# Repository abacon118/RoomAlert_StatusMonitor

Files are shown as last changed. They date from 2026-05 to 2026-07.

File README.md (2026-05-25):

# Room Alert and Web Service Status Display/Monitor
ESP32 based status monitor for RoomAlert Temperature monitors and HTTP/HTTPS based web services
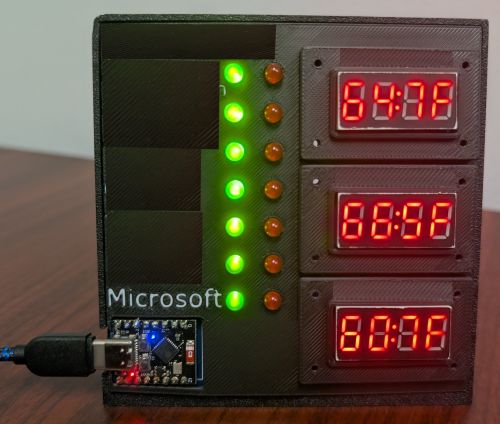
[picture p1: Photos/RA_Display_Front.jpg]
RA_Display_Front
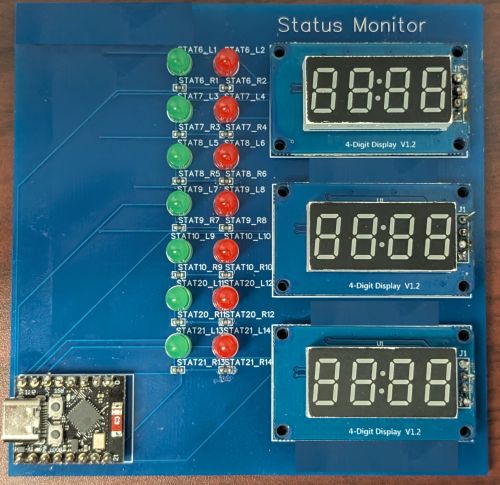
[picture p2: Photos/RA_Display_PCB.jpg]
RA_Display_PCB
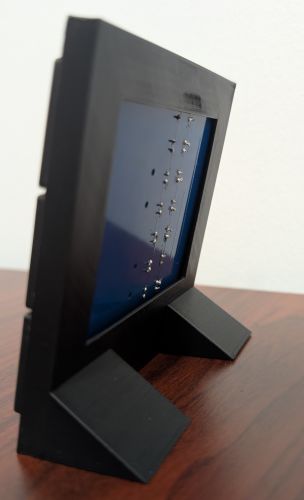
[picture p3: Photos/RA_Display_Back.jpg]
RA_Display_Back
  

## Setup
1. [Install MicroPython on ESP32](https://micropython.org/download/ESP32_GENERIC_C3/)
2. Download or copy [RA_StatusMonitor.py](/RA_StatusMonitor.py) and [config.json](/config.json)
3. Edit the following lines of config.json
     - Line 3 - Your Wifi SSID
     - Line 4 - Your Wifi Password
     - Lines 6-9 - Replace with your Room Alert links. You must create a public URL for your Room Alert device.  Paste the URL(s) in line 10 of the code.
     - Lines 11-17 - Replace with the web services/sites you wish to monitor.  Note: You can monitor services using alternate ports such as 4433, 8080, 8443, etc. as long as it uses a TCP connection.
5. Copy [tm1637.py](/tm1637.py) to ESP32.  Source: [https://github.com/mcauser/micropython-tm1637](https://github.com/mcauser/micropython-tm1637)
6. Save RA_StatusMonitor.py as boot.py on the ESP32 using Thonny or another similar IDE.

## Parts
- 3x [TM1637 4 bit 7 segment display](https://www.aliexpress.us/item/3256805913248771.html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)
- 1x [ESP 32 C3 Super Mini](https://www.aliexpress.us/item/3256807754944428.html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)
- 7x Red LEDs
- 7x Green LEDs
- 14x 220 Ohm 0603 Resistors

## Schematic
[Schematic PDF](/Gerber_RoomAlert_Generic_PCB_1-copy_2026-05-15.pdf)
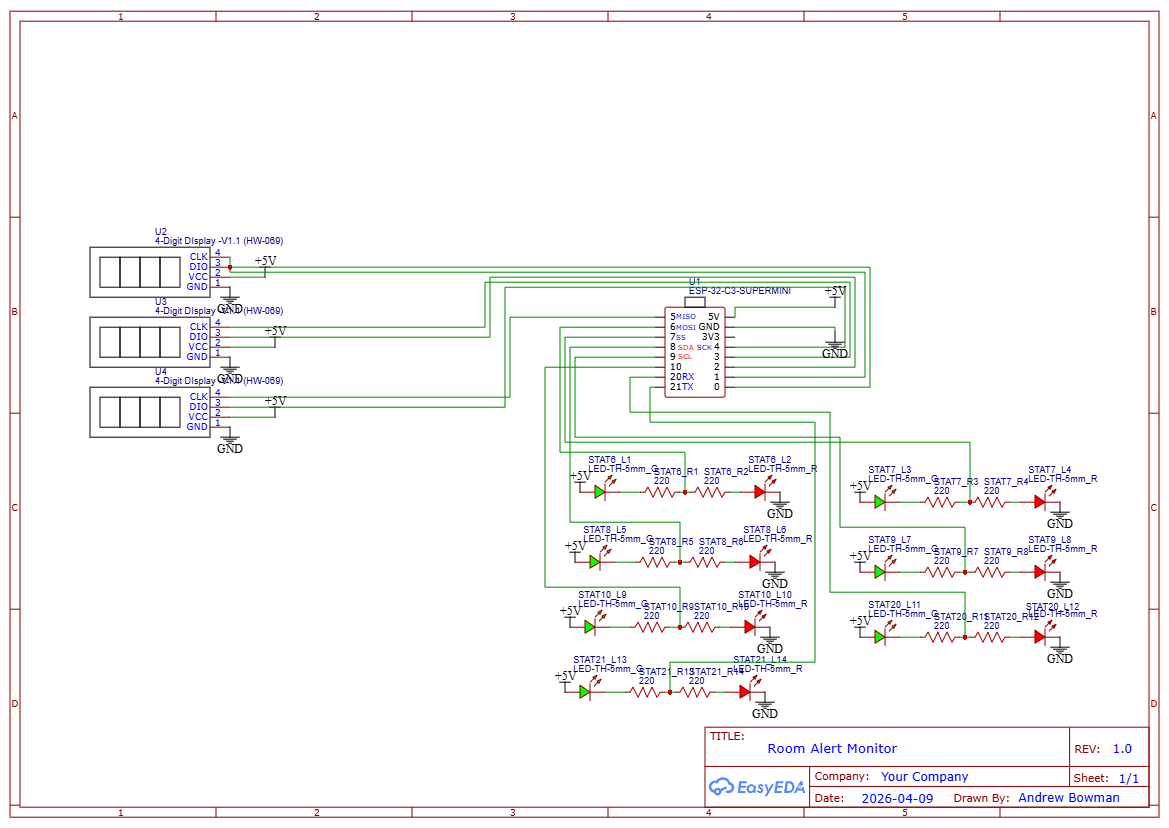
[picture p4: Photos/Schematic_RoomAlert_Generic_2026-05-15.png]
Schematic


## PCB
[Gerber ZIP](/Gerber_RoomAlert_Generic_PCB_1-copy_2026-05-15.zip)
[EasyEDA Files](/RoomAlert_EasyEDA.zip)
100mm x 100mm Standard 2 layer PCB from JLC PCB
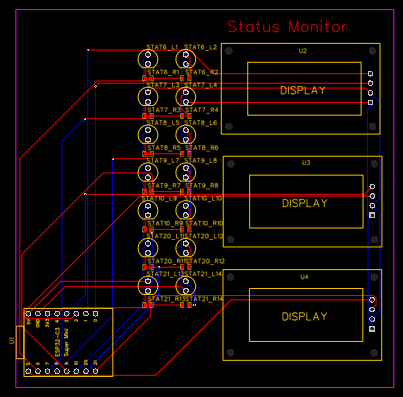
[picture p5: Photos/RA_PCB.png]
PCB


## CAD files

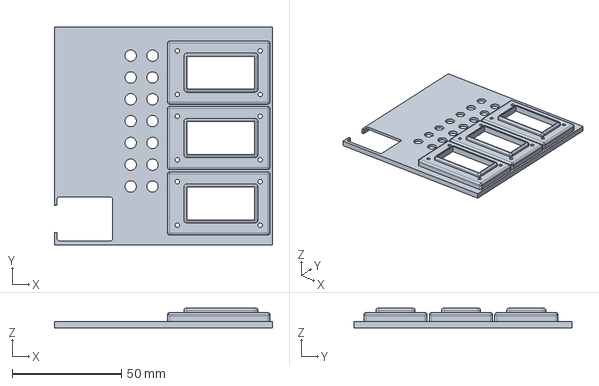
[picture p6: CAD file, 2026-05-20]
3dPrint/RA_Display_Blank.FCStd
100.0 x 100.0 x 9.00 mm

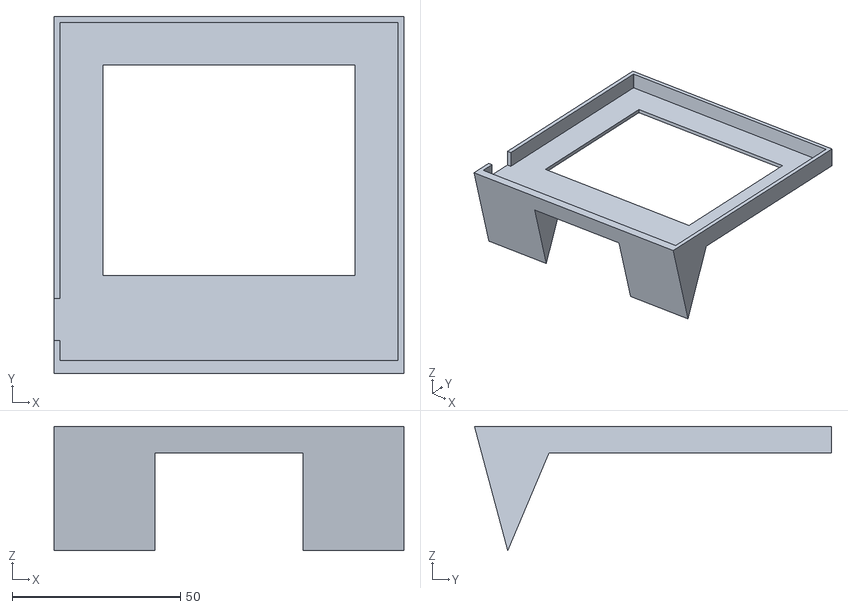
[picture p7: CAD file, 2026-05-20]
3dPrint/RA_Display_Blank-Back.stl
104.0 x 106.1 x 37.0

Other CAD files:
3dPrint/RA_Display_Blank-Body.stl

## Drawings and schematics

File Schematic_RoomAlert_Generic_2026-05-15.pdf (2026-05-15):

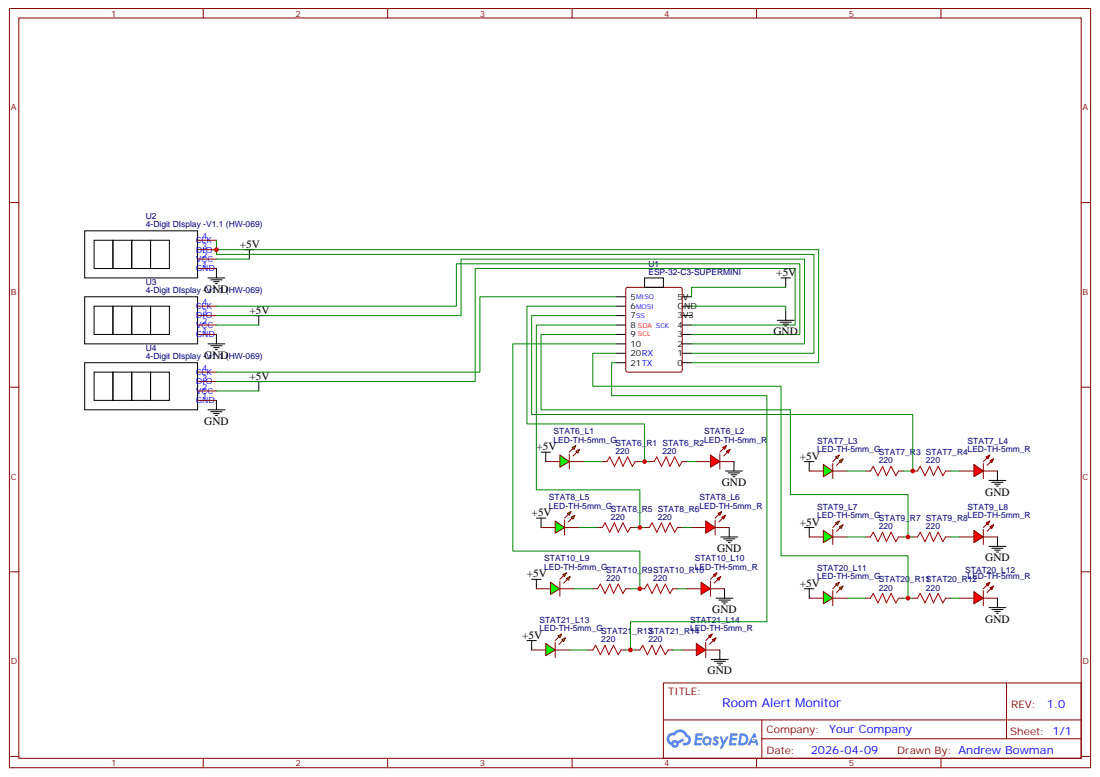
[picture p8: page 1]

Drawn By: Andrew Bowman

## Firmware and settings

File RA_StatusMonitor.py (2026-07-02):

# Room Alert ESP32 Monitor V4.2
# Andrew Bowman 2026
# https://docs.sunfounder.com/projects/umsk/en/latest/04_pi_pico/pico_lesson26_lcd.html
# https://microcontrollerslab.com/micropython-openweathermap-api-esp32-esp8266-sensorless-weather-station/
# AI assistance from Copilot was used in the creation of this.
import time
import socket
import tm1637
import _thread
from machine import Pin
tm = [
    tm1637.TM1637(clk=Pin(1), dio=Pin(0)),
    tm1637.TM1637(clk=Pin(3), dio=Pin(2)),
    tm1637.TM1637(clk=Pin(5), dio=Pin(4))
]

try:
  import urequests as requests
except:
  import requests
  
try:
  import ujson as json
except:
  import json

import network

import esp
esp.osdebug(None)

import gc
gc.collect()

led6 = Pin(6, Pin.OUT)
led7 = Pin(7, Pin.OUT)
led8 = Pin(8, Pin.OUT)
led9 = Pin(9, Pin.OUT)
led10 = Pin(10, Pin.OUT)
led20 = Pin(20, Pin.OUT)
led21 = Pin(21, Pin.OUT)

led6.value(1)
led7.value(1)
led8.value(1)
led9.value(1)
led10.value(1)
led20.value(1)
led21.value(1)

with open("config.json") as f:
    config = json.load(f)
RA_URLs = []
for entry in config["RA_URLs"]:
    RA_URLs.append({
        "url": entry["url"],
        "location": entry["location"]        
    })
PING_URLs = []
for entry in config["PING_TARGETS"]:
    PING_URLs.append({
        "url": entry["url"],
        "port": entry["port"],
        "led": Pin(entry["led"], Pin.OUT)
    })
ssid = config["wifi"]["ssid"]
password = config["wifi"]["password"]

station = network.WLAN(network.STA_IF)

station.active(True)
station.connect(ssid, password)

while station.isconnected() == False:
  pass

print('Connection successful')
print(station.ifconfig())


def print_temp(display, f):

    if f < -9.9:
        display.show('lo')
        return
    if f > 99.9:
        display.show('hi')
        return
    raw = "{:4.2f}".format(f)   # e.g. "67.7"     # Format with one decimal
    dot_pos = raw.index('.')    # e.g. 2     # Find decimal BEFORE removing it
    s = raw.replace('.', '')    # "677"     # Remove the dot
    segs = display.encode_string(s)     # Encode the digits (3 digits + 1 blank)
    segs[dot_pos - 1] |= 0x80     # Add decimal point to the correct digit
    segs[-1] = 0b01110001      # Replace last digit with raw segment pattern for 'F'
    display.write(segs)     # Write raw segments directly

def tcp_ping(host, port=80, timeout=2000):
    addr = socket.getaddrinfo(host, port)[0][-1]
    s = socket.socket()
    s.settimeout(timeout / 1000)

    start = time.ticks_ms()
    try:
        s.connect(addr)
        s.close()
        return True, time.ticks_diff(time.ticks_ms(), start)
    except Exception as e:
        return False, str(e)
    finally:
        s.close()

while(1):
    for i, entry in enumerate(RA_URLs):
        url = entry["url"]
        location = entry["location"]

        RA_data = requests.get(url)
        RA_text = RA_data.text
        RA_data.close()
        del RA_data
        gc.collect()
        #print(RA_data.text)
        marker = "                                            <b>" #Find this on line 265 in the Room Alert HTML.  The Temp is right after it.
        start = RA_text.find(marker)

        if start != -1:
            start += len(marker)
            end = RA_text.find("°F", start)
            Temp = float(RA_text[start:end].strip())
            print(location," temperature:", Temp)
            print_temp(tm[i],Temp)
        else:
            print("Temperature not found")
            
    for entry in PING_URLs:
            host = entry["url"]
            port = entry["port"]
            led = entry["led"]
            ok, info = tcp_ping(host, port)
            if ok:
                print(host, "reachable, latency:", info, "ms")
                led.value(0)
            else:
                print(host, "UNREACHABLE:", info)
                led.value(1)
            
    time.sleep(60)

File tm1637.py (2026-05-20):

"""
MicroPython TM1637 quad 7-segment LED display driver
https://github.com/mcauser/micropython-tm1637

MIT License
Copyright (c) 2016-2023 Mike Causer

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
__version__ = '1.3.0'

from micropython import const
from machine import Pin
from time import sleep_us, sleep_ms

TM1637_CMD1 = const(64)  # 0x40 data command
TM1637_CMD2 = const(192) # 0xC0 address command
TM1637_CMD3 = const(128) # 0x80 display control command
TM1637_DSP_ON = const(8) # 0x08 display on
TM1637_DELAY = const(10) # 10us delay between clk/dio pulses
TM1637_MSB = const(128)  # msb is the decimal point or the colon depending on your display

# 0-9, a-z, blank, dash, star
_SEGMENTS = bytearray(b'\x3F\x06\x5B\x4F\x66\x6D\x7D\x07\x7F\x6F\x77\x7C\x39\x5E\x79\x71\x3D\x76\x06\x1E\x76\x38\x55\x54\x3F\x73\x67\x50\x6D\x78\x3E\x1C\x2A\x76\x6E\x5B\x00\x40\x63')

class TM1637(object):
    """Library for quad 7-segment LED modules based on the TM1637 LED driver."""
    def __init__(self, clk, dio, brightness=7):
        self.clk = clk
        self.dio = dio

        if not 0 <= brightness <= 7:
            raise ValueError("Brightness out of range")
        self._brightness = brightness

        self.clk.init(Pin.OUT, value=0)
        self.dio.init(Pin.OUT, value=0)
        sleep_us(TM1637_DELAY)

        self._write_data_cmd()
        self._write_dsp_ctrl()

    def _start(self):
        self.dio(0)
        sleep_us(TM1637_DELAY)
        self.clk(0)
        sleep_us(TM1637_DELAY)

    def _stop(self):
        self.dio(0)
        sleep_us(TM1637_DELAY)
        self.clk(1)
        sleep_us(TM1637_DELAY)
        self.dio(1)

    def _write_data_cmd(self):
        # automatic address increment, normal mode
        self._start()
        self._write_byte(TM1637_CMD1)
        self._stop()

    def _write_dsp_ctrl(self):
        # display on, set brightness
        self._start()
        self._write_byte(TM1637_CMD3 | TM1637_DSP_ON | self._brightness)
        self._stop()

    def _write_byte(self, b):
        for i in range(8):
            self.dio((b >> i) & 1)
            sleep_us(TM1637_DELAY)
            self.clk(1)
            sleep_us(TM1637_DELAY)
            self.clk(0)
            sleep_us(TM1637_DELAY)
        self.clk(0)
        sleep_us(TM1637_DELAY)
        self.clk(1)
        sleep_us(TM1637_DELAY)
        self.clk(0)
        sleep_us(TM1637_DELAY)

    def brightness(self, val=None):
        """Set the display brightness 0-7."""
        # brightness 0 = 1/16th pulse width
        # brightness 7 = 14/16th pulse width
        if val is None:
            return self._brightness
        if not 0 <= val <= 7:
            raise ValueError("Brightness out of range")

        self._brightness = val
        self._write_data_cmd()
        self._write_dsp_ctrl()

    def write(self, segments, pos=0):
        """Display up to 6 segments moving right from a given position.
        The MSB in the 2nd segment controls the colon between the 2nd
        and 3rd segments."""
        if not 0 <= pos <= 5:
            raise ValueError("Position out of range")
        self._write_data_cmd()
        self._start()

        self._write_byte(TM1637_CMD2 | pos)
        for seg in segments:
            self._write_byte(seg)
        self._stop()
        self._write_dsp_ctrl()

    def encode_digit(self, digit):
        """Convert a character 0-9, a-f to a segment."""
        return _SEGMENTS[digit & 0x0f]

    def encode_string(self, string):
        """Convert an up to 4 character length string containing 0-9, a-z,
        space, dash, star to an array of segments, matching the length of the
        source string."""
        segments = bytearray(len(string))
        for i in range(len(string)):
            segments[i] = self.encode_char(string[i])
        return segments

    def encode_char(self, char):
        """Convert a character 0-9, a-z, space, dash or star to a segment."""
        o = ord(char)
        if o == 32:
            return _SEGMENTS[36] # space
        if o == 42:
            return _SEGMENTS[38] # star/degrees
        if o == 45:
            return _SEGMENTS[37] # dash
        if o >= 65 and o <= 90:
            return _SEGMENTS[o-55] # uppercase A-Z
        if o >= 97 and o <= 122:
            return _SEGMENTS[o-87] # lowercase a-z
        if o >= 48 and o <= 57:
            return _SEGMENTS[o-48] # 0-9
        raise ValueError("Character out of range: {:d} '{:s}'".format(o, chr(o)))

    def hex(self, val):
        """Display a hex value 0x0000 through 0xffff, right aligned."""
        string = '{:04x}'.format(val & 0xffff)
        self.write(self.encode_string(string))

    def number(self, num):
        """Display a numeric value -999 through 9999, right aligned."""
        # limit to range -999 to 9999
        num = max(-999, min(num, 9999))
        string = '{0: >4d}'.format(num)
        self.write(self.encode_string(string))

    def numbers(self, num1, num2, colon=True):
        """Display two numeric values -9 through 99, with leading zeros
        and separated by a colon."""
        num1 = max(-9, min(num1, 99))
        num2 = max(-9, min(num2, 99))
        segments = self.encode_string('{0:0>2d}{1:0>2d}'.format(num1, num2))
        if colon:
            segments[1] |= 0x80 # colon on
        self.write(segments)

    def temperature(self, num):
        if num < -9:
            self.show('lo') # low
        elif num > 99:
            self.show('hi') # high
        else:
            string = '{0: >2d}'.format(num)
            self.write(self.encode_string(string))
        self.write([_SEGMENTS[38], _SEGMENTS[12]], 2) # degrees C
        
    def temperature_f(self, num):
        if num < -9:
            self.show('lo') # low
        elif num > 99:
            self.show('hi') # high
        else:
            string = '{0: >2d}'.format(num)
            self.write(self.encode_string(string))
        self.write([_SEGMENTS[38], _SEGMENTS[15]], 2) # degrees F

    def show(self, string, colon=False):
        segments = self.encode_string(string)
        if len(segments) > 1 and colon:
            segments[1] |= 128
        self.write(segments[:4])

    def scroll(self, string, delay=250):
        segments = string if isinstance(string, list) else self.encode_string(string)
        data = [0] * 8
        data[4:0] = list(segments)
        for i in range(len(segments) + 5):
            self.write(data[0+i:4+i])
            sleep_ms(delay)
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

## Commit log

2026-05-15 Add PCB Gerber
2026-05-15 Add ESP32 setup instructions to README
    Added setup instructions for ESP32 to the README.
2026-05-20 Clarify library copy instructions for ESP32
    Updated instructions for copying libraries to ESP32 with a link to the source.
2026-05-20 Add images to README for Room Alert project
    Added images of the Room Alert display and PCB to the README.
2026-05-20 Add 3d print files
    [RA_Display_Blank-Back.stl, RA_Display_Blank-Body.stl, RA_Display_Blank.FCStd]
2026-06-07 Update RA_StatusMonitor.py
    Add garbage collection and fix memory errors
    [RA_StatusMonitor.py]
